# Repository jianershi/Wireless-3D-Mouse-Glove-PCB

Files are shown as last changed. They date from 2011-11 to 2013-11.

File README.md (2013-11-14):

#Wireless 3D Mouse on a Glove PCB

A wireless 3D mouse that is able to track orientations of each fingers. All orientation calculation ins done on the onboard Atmel 32bit MCU. 

This repo inclues all hardware design files using [Altium Designer](www.altium.com/en/products/altium-designer).

rep

##Background
[2011 Senior Design Project](http://courses.engr.illinois.edu/ece445/?f=Projects&sem=fall2011&proj=17#a17)

This project is combined effort of [Jianer Shi](https://github.com/paulshi) & [Borui Chen](https://github.com/boruichen)

##Design Documentation
http://paulshi.me/projects/wireless3dmouse/

Bitdeli Badge (https://bitdeli.com/free "Bitdeli Badge")

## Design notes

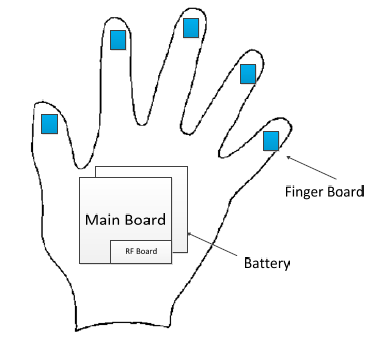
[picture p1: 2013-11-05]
handside.png

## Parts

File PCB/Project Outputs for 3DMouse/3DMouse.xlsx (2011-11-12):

Comment | Description | Designator | Footprint | LibRef | Quantity | Value
Header 4X2 | Header, 4-Pin, Dual row | 2.4G | HDR2X4 | Header 4X2 | 1
TPS7333Q |  | 3.3V Power Source | SOIC127P600-8BN | TPS7333Q | 1
Header 2 | Header, 2-Pin | Battery, NMI, Reset, UART | HDR1X2 | Header 2 | 4
Cap Pol1 | Polarized Capacitor (Radial) | C1 | TC7343-2917 | Cap Pol1 | 1 | 10uF
Cap Semi | Capacitor (Semiconductor SIM Model) | C2, C3, C4, C5, C6, C7, C8, C9, C10, C11, C12, C13, C14 | CAPC2012N | Cap Semi | 13 | .1uF, 1nF, 2.2uF, 4.7uF, 22pF, 470pF
LED2 | Typical RED, GREEN, YELLOW, AMBER GaAs LED | D1 | RESC3216N | LED2 | 1
Header 5X2 | Header, 5-Pin, Dual row | FB_Power, FB_TWIs | HDR2X5 | Header 5X2 | 2
Header 3X2 | Header, 3-Pin, Dual row | JTAG | HDR2X3 | Header 3X2 | 1
Mini USB |  | Mini-USB | MINI USB | Mini USB | 1
Header 1-16 | Header, 8-Pin, Dual row | P1 | HDR2X8 | Header 8X2 | 1
Header 17-32 | Header, 8-Pin, Dual row | P2 | HDR2X8 | Header 8X2 | 1
Header 33-48 | Header, 8-Pin, Dual row | P3 | HDR2X8 | Header 8X2 | 1
Header 49-64 | Header, 8-Pin, Dual row | P4 | HDR2X8 | Header 8X2 | 1
Header 5 | Header, 5-Pin | P5 | HDR1X5 | Header 5 | 1
Header 4 | Header, 4-Pin | P6 | HDR1X4 | Header 4 | 1
Header 8 | Header, 6-Pin | P7 | HDR1X6 | Header 6 | 1
Header 7 | Header, 8-Pin | P8 | HDR1X8 | Header 8 | 1
P_OnBoard Sensor | Header, 2-Pin | P_OnBoard Sensor | HDR1X2 | Header 2 | 1
Res3 | Resistor | R1, R2, R3, R4, R5, R6, R7, R8, R9, R10, R11, R12, R13, R14, R15, R16, R17, R18, R19, R20, R21, R22, R23 | RESC2012N | Res3 | 23 | 1k, 10k, 39, 80.6
SW-SPDT | SPDT Subminiature Toggle Switch, Right Angle Mounting, Vertical Actuation | S1 | 563-1102-1-ND | SW-SPDT | 1
74LV4051 |  | SCL MUX/DEMUX, SDA MUX/DEMUX | SOIC127P600-16N | 74LV4051 | 2
TWI_OnBoard Sensor | Header, 2-Pin | TWI_OnBoard Sensor | HDR1X2 | Header 2 | 1
AT32UC3B0256-A2UT | 32-bit AVR UC3 B Series Microcontroller, 256KB Flash, 32KB SRAM, 44 GPIO pins, Industrial Grade, 64-Pin TQFP, Tray | U1 | TQFP64_N - ECESHOP | AT32UC3B0256-A2UT | 1
XTAL 12Mhz | Crystal Oscillator | Y1 | HC-49U - Through Hole | XTAL | 1
XTAL 32.768khz | Crystal Oscillator | Y2 | XTAL32.768 | XTAL | 1

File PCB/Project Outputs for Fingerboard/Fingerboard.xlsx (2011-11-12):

Comment | Description | Designator | Footprint | LibRef | Quantity | Value
BMA180 |  | Accel | BMA180 - ECESHOP | BMA180 | 1
Cap Semi | Capacitor (Semiconductor SIM Model) | C16, C17, C19, C20, C21, C22 | CAPC2012N | Cap Semi | 6 | .1uF, 0.022uF, 2.2nF, 10nF, 220nF
Cap Pol1 | Polarized Capacitor (Radial) | C18 | TC3528-1411 | Cap Pol1 | 1 | 4.7uF
IMU3000 |  | Gyro | IMU3000 - ECESHOP | IMU3000 | 1
INT | Header, 3-Pin | INT | HDR1X3 | Header 3 | 1
HMC5883L |  | MAG | HMC5883L - ECESHOP | HMC5883L | 1
Header 2 | Header, 2-Pin | Power | HDR1X2 | Header 2 | 1
TWI | Header, 2-Pin | TWI | HDR1X2 | Header 2 | 1

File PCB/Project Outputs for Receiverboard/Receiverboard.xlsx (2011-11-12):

Comment | Description | Designator | Footprint | LibRef | Quantity | Value
Cap Semi | Capacitor (Semiconductor SIM Model) | C1, C2, C3, C4, C5, C6, C7 | CAPC2012L | Cap Semi | 7 | .1uF, 4.7uF, 10nF, 22pF
Cap Pol3 TANT | Polarized Capacitor (Surface Mount) | C8, C9 | CAPC3216N | Cap Pol3 | 2 | 10uF, 15uF
Ferrite Bead 1A |  | Ferrite | RESC2012N | Ferrite Bead | 1
Header 3X2 | Header, 3-Pin, Dual row | ISP | HDR2X3 | Header 3X2 | 1
Header 2 | Header, 2-Pin | Mech1, Mech2 | HDR1X2 | Header 2 | 2
Mini USB |  | MiniUSB | MINI USB | Mini USB | 1
Res3 | Resistor | R1, R2, R3, R4 | RESC2012N | Res3 | 4 | 10k, 200
Header 4X2 | Header, 4-Pin, Dual row | RF Board | HDR2X4 | Header 4X2 | 1
LED2 | Typical RED, GREEN, YELLOW, AMBER GaAs LED | RXD | RESC3216N | LED2 | 1
LED2 | Typical RED, GREEN, YELLOW, AMBER GaAs LED | TXD | RESC1608N | LED2 | 1
ATmega8L-8AI | 8-Bit AVR Microcontroller with 8K Bytes of In-System Programmable Flash Memory | U1 | 32A_N | ATmega8L-8AI | 1
FT232RL-Reel | USB UART Asynchronous Serial Data Transfer Chip, SSOP-28, Tape and Reel | U2 | SSOP-28_N | FT232RL-Reel | 1
LM1117MPX-3.3 | 800mA Low-Dropout Linear Regulator, 4-pin SOT-223 | U3 | MP04A_N | LM1117MPX-3.3 | 1
XTAL 8Mhz | Crystal Oscillator | Y1 | HC-49U - SMD | XTAL | 1

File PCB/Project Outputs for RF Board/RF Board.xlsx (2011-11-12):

Comment | Description | Designator | Footprint | LibRef | Quantity | Value
nRF24L01+ |  | 2.4Ghz Chip | nRF24L01+ | nRF24L01+ | 1
Cap Semi | Capacitor (Semiconductor SIM Model) | C1, C2, C3, C4, C5, C6, C7, C8, C9 | CAPC2012N | Cap Semi | 9 | 1.5pF, 1nF, 1pF, 2.2nF, 4.7pF, 10nF, 22pF, 33nF
Inductor | Inductor | L1, L2, L3 | INDC1608N | Inductor | 3 | 2.7nH, 3.9nH, 8.2nH
Header 4X2 | Header, 4-Pin, Dual row | P1 | HDR2X4 | Header 4X2 | 1
Res2 | Resistor | R1 | RESC2012N | Res2 | 1 | 1M
Res3 | Resistor | R2 | RESC2012N | Res3 | 1 | 22K
16Mhz | Crystal Oscillator | X1 | HC-49U - Through Hole | XTAL | 1

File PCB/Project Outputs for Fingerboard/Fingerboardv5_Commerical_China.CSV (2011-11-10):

Bill of Material for
On 11/7/2011 at 1:04:34 PM
Comment | Pattern | Quantity | Components
BMA180 | BMA180 - ECESHOP | 1 | Accel
Cap Pol1 | TC3528-1411 | 1 | C18 | Polarized Capacitor (Radial)
Cap Semi | CAPC2012N | 6 | C16, C17, C19, C20, C21, C22 | Capacitor (Semiconductor SIM Model)
Header 2 | HDR1X2 | 1 | Power | Header, 2-Pin
HMC5883L | HMC5883L - ECESHOP | 1 | MAG
IMU3000 | IMU3000 - ECESHOP | 1 | Gyro
TWI | HDR1X2 | 1 | TWI | Header, 2-Pin

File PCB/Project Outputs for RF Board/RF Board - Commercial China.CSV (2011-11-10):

Bill of Material for
On 11/7/2011 at 1:00:49 PM
Comment | Pattern | Quantity | Components
16Mhz | HC-49U - Through Hole | 1 | X1 | Crystal Oscillator
Cap Semi | CAPC2012N | 9 | C1, C2, C3, C4, C5, C6, C7, C8, C9 | Capacitor (Semiconductor SIM Model)
Header 4X2 | HDR2X4 | 1 | P1 | Header, 4-Pin, Dual row
Inductor | INDC1608N | 3 | L1, L2, L3 | Inductor
nRF24L01+ | nRF24L01+ | 1 | 2.4Ghz
Res2 | RESC2012N | 1 | R1 | Resistor
Res3 | RESC2012N | 1 | R2 | Resistor

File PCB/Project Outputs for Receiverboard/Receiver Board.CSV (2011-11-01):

Bill of Material for
On 10/31/2011 at 7:42:44 PM
Comment | Pattern | Quantity | Components
ATmega8L-8AI | 32A_N | 1 | U1 | 8-Bit AVR Microcontroller with 8K Bytes of In-System Programmable Flash Memory
Cap Pol3 TANT | capc3216n | 2 | C8, C9 | Polarized Capacitor (Surface Mount)
Cap Semi | CAPC2012L | 7 | C1, C2, C3, C4, C5, C6, C7 | Capacitor (Semiconductor SIM Model)
Ferrite Bead 1A | RESC2012N | 1 | Ferrite
FT232RL-Reel | SSOP-28_N | 1 | U2 | USB UART Asynchronous Serial Data Transfer Chip, SSOP-28, Tape and Reel
Header 3X2 | HDR2X3 | 1 | ISP | Header, 3-Pin, Dual row
Header 4X2 | HDR2X4 | 1 | RF Board | Header, 4-Pin, Dual row
LED2 | RESC1608N | 1 | TXD | Typical RED, GREEN, YELLOW, AMBER GaAs LED
LED2 | RESC3216N | 1 | RXD | Typical RED, GREEN, YELLOW, AMBER GaAs LED
LM1117MPX-3.3 | MP04A_N | 1 | U3 | 800mA Low-Dropout Linear Regulator, 4-pin SOT-223
Mini USB | MINI USB | 1 | MiniUSB
Res3 | RESC2012N | 4 | R1, R2, R3, R4 | Resistor
XTAL 8Mhz | HC-49U - SMD | 1 | Y1 | Crystal Oscillator

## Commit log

2011-09-21 some initial work, imu 3000 and bma 180 component drawn by hand
    [3DMouse.PrjPcb, BMA180.SchLib, IMU3000.SchLib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]
2011-09-22 gyro drawing done
    [3DMouse.PrjPcb, BMA180.SchDoc, IMU3000.SchDoc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]
2011-09-22 finger board schematic done
    [3.3V Power Supply.SchDoc, 3DMouse.PrjPcb, BMA180.SchDoc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]
2011-09-22 3.3V power source done
    [3.3V Power Supply.SchDoc, 3D Mouse Main Controller.SchDoc, 3DMouse.PrjPcb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]
2011-09-22 call it for a day
    [3D Mouse Main Controller.SchDoc, 3DMouse.PrjPcb, nRF24L01+.SchDoc]
2011-09-22 save before going to cs431 lab
    [2.4ghz Receiver Board.SchDoc, 3DMouse.PrjPcb, nRF24L01+.SchDoc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]
2011-09-27 receiver board done
    [2.4Ghz Chip Board.SchDoc, 2.4ghz Receiver Board.SchDoc, 3.3V Power Supply.SchDoc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]
2011-09-27 let me start designing the main board
    [2.4Ghz Chip Board.SchDoc, 2.4ghz Receiver Board.SchDoc, 3D Mouse Main Controller.SchDoc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]
2011-10-11 call it a day
    [2.4Ghz Chip Board.SchDoc, 2.4ghz Receiver Board.SchDoc, 3D Mouse Main Controller.SchDoc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]
2011-10-14 i think i fixed the sub bus mux, need to delte the old graph, also, need to draw magnetometer circuit. fix fingerboard+mainboard magnetometer part
    [3DMouse.PrjPcb, 3DMouseMainBoardAssembly.SchDoc, 74LV4051.SchLib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]
2011-10-15 magnetometer added, need to fix the footprint for CAN capacitor SMD on magnetometer, ask andy. need to review
    [3DMouse.PrjPcb, 3DMouseMainBoardAssembly.SchDoc, Accelerometer and Gyro on Main Controller.SchDoc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]
2011-10-15 miner fix up
    [3DMouse.PrjPcb, BMA180.SchDoc, HMC5883L.SchDoc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]
2011-10-16 capacitor all done. fixing resistor next, and then inductor
    [2.4ghz Receiver Board.SchDoc, 3.3V Power Supply.SchDoc, 3DMouse.PrjPcb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]
2011-10-18 handdrawn mainboard PCB finished, need revision/check
    [2.4Ghz Chip Board.SchDoc, 2.4ghz Receiver Board.SchDoc, 3.3V Power Supply.SchDoc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]
2011-10-20 10/20 12:04am, fingerboard done
    [3DMouse.PrjPcb, BMA180.PcbLib, BMA180.SchDoc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]
2011-10-25 finger print made, need to change ALL FOOTPRINT (CAP/REG) TO LOW DENSITY before sent out for commercial making
    [2.4Ghz Chip Board.SchDoc, 2.4ghz Receiver Board.SchDoc, Fingerboard.PrjPcb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]
2011-10-25 RF board modified, need to check with machine shop 0805(2012) 1M resistor supply before sending the new design to mark
    [RF Board - ECESHOP.PcbDoc, nRF24L01+.SchDoc]
2011-10-25 modified RF board, increased the width, ECEshop does have 0805(2012) 1M Om resistor in one of the folders
    [RF Board - ECESHOP.PcbDoc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]
2011-10-26 fixed all capacitor/resistors footprint on the 3D main controller, but the footprint on the potential breakout board is still old. not sure will implement breakout board after all, require so much co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
    [3.3V Power Supply.SchDoc, AT32UC3B0256 Breakout Top Assembly.SchDoc, AT32UC3B0256 Breakout.PcbDoc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]
2011-10-26 rule successful, autoroute successful on the main board
    [3DMouse.PrjPcb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]
2011-10-26 good placement, unrouted version
    [Main Board.SchDoc, PCB1.PcbDoc]
2011-10-26 decide to use this autorouted main board version, order placed with advanced circuit
    [3DMouse.PrjPcb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]
2011-10-28 Receiver board PCB laid out (v1), sent to ECESHOP, RF board modified (2nd version) sent to ECEshop
    [2.4ghz Receiver Board.SchDoc, 3DMouse.PrjPcb, 5V to 3.3V.SchDoc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]
2011-10-29 fixed footprint for Mini USB
    [2.4ghz Receiver Board.SchDoc, 3DMouse.PrjPcb, Fingerboard.PrjPcb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]
2011-10-30 nrf24l01+ footprint fixed, RF board updated
    [2.4Ghz Chip Board.SchDoc, RF Board - ECESHOP.PcbDoc, RF Board.PrjPcb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]
2011-10-31 bma180 footprint fixed
    [3DMouse.PrjPcb, BMA180.PcbLib, BMA180.SchDoc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]
2011-10-31 hmc5883l footprint fixed, rf board, main board not fixed
    [Fingerboardv2.PcbDoc, HMC5883L.PcbLib, HMC5883L.SchDoc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]
2011-10-31 imu3000 footprint redrawn. updated to schematics, not updated to pcb yet
    [3DMouse.PrjPcb, Fingerboardv2.PcbDoc, IMU3000.PcbLib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]
2011-10-31 Receiver board completely verified and done
    [2.4ghz Receiver Board.SchDoc, 5V to 3.3V.SchDoc, Receiver Board.PcbDoc]
2011-10-31 finalized RF Board
    [2.4ghz Receiver Board.SchDoc, 3DMouse.PrjPcb, Receiver Board.PcbDoc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]
2011-10-31 cleaned up
    [Receiver Board.PcbDoc, Receiverboard.PrjPcb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]
2011-11-01 new revision of receiver board, fixed some space tensions
    [Receiver Board.CSV, Receiver Board.PcbDoc, Receiverboard.PrjPcb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]
2011-11-01 fingerboard v4 done, obviously this version looks terrible
    [BMA180.SchDoc, Fingerboard.PrjPcb, Fingerboardv3.PcbDoc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]
2011-11-01 new fingerboard done. updated bma180 footprint
    [BMA180.PcbLib, BMA180.SchDoc, BMA180.SchLib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]
2011-11-01 RF Board fixed. extended the nrf24l01+ footprint a little bit
    [2.4Ghz Chip Board.SchDoc, RF Board - ECESHOP.PcbDoc, RF Board.PrjPcb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]
2011-11-01 fixed one wire on the RF Board, which should all on the same layer for all pins
    [RF Board - ECESHOP.PcbDoc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]
2011-11-02 checked schematics and footprint for 74lv4051, tps7333q, ready to make new main board
    [3.3V Power Supply.SchDoc, 3DMouse.PrjPcb, 74LV4051.SchLib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]
2011-11-03 new main board eceshop first version
    [3DMouse.PrjPcb, 3DMouseMainBoardAssembly.SchDoc, AT32UC3B0256.PcbLib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]
2011-11-03 main board ece shop (for development) done. need to double, triple check before send in
    [Main Board ECEshop.PcbDoc]
2011-11-03 eceshop main board v0.1 submitted
    [3DMouse.PrjPcb, I2C_BUS_MUX.SchDoc, Main Board ECEshop.PcbDoc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]
2011-11-03 increased polygon spacing to 1.5mm for mainboard (eceshop)
    [Main Board ECEshop.PcbDoc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]
2011-11-05 union the power and twi connector in fingerboard eceshop version. finished commercial (china) version of fingerboard
    [3DMouse.xlsx, Fingerboard.PrjPcb, Fingerboard.xlsx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]
2011-11-05 receiver board commercial v (china) done, some small changes to commercial v(china) on fingerboard
    [Fingerboard.PrjPcb, Fingerboardv5_Commerical_China.PcbDoc, Receiver Board - Commercial China.PcbDoc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]
2011-11-06 RF board (china commerial v.) done, some modifications to the china commercial v. of fingerboard and receiver board
    [Fingerboardv5_Commerical_China.PcbDoc, RF Board - Commercial China.PcbDoc, RF Board.PrjPcb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]
2011-11-07 new main board done
    [3DMouse.PrjPcb, Board Assembly.PcbDoc, Fingerboardv5_Commerical_China.PcbDoc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]
2011-11-10 changes to mainboard, change to reset circuit, add NMI for usb bootloader
    [3.3V Power Supply.SchDoc, 3DMouse.PrjPcb, 3DMouse.xls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]
2011-11-12 forgot what i edited, anyway, those board sent for manufactory
    [3DMouse.PrjPcb, 3DMouse.xls, 3DMouse.xlsx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]
2011-11-25 nothing really
    [RF Board.PrjPcb, Receiverboard.PrjPcb]
